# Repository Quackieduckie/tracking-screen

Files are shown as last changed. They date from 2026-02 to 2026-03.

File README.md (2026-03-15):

# Tracking Screen

A screen that follows you around the room. It can be used as a personal assistant, to display data, or simply to watch movies without needing to constantly adjust the angle — it self-calibrates to keep the view optimal.

**Made possible thanks to [PCBWay](https://www.pcbway.com/) for their support in making this project a reality.**

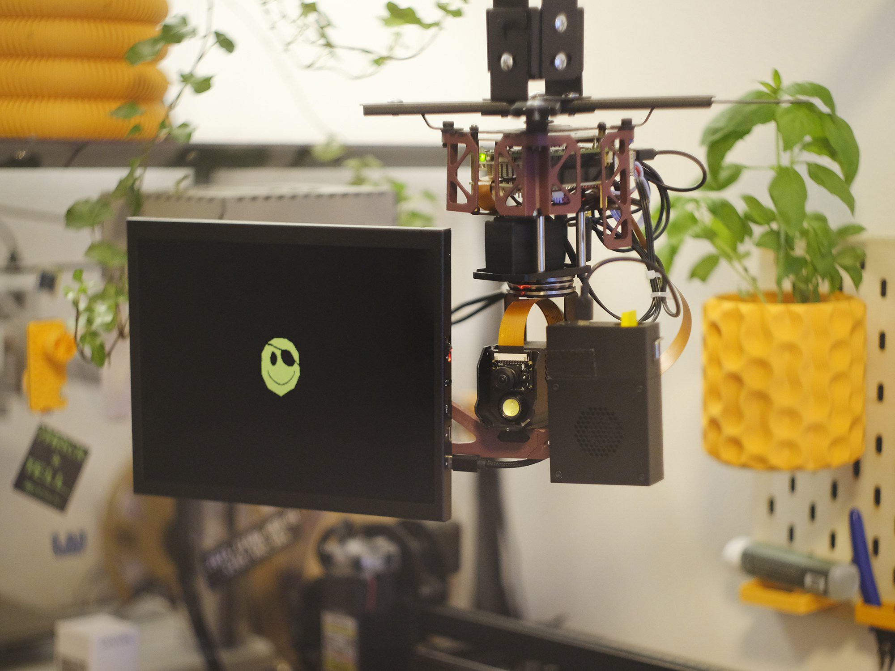
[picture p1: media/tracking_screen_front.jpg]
Tracking Screen


## Background

I first had this idea after catching a cold while visiting my old hackerspace in Berlin, [c-base](https://c-base.org/), and having to spend a few days in bed. I thought it would be cool to have a robotic screen that can track faces, and that you can reposition using hand commands. I could also see this as a kind of digital assistant, although I personally don't see the use case for myself yet.

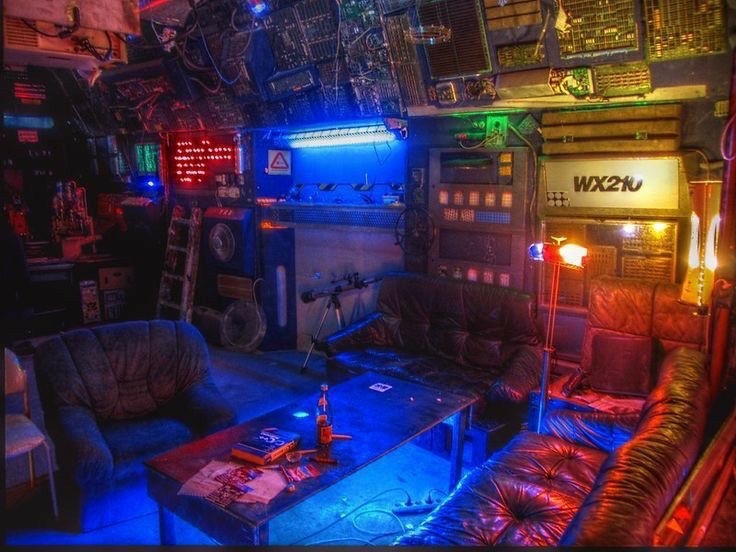
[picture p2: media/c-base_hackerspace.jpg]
c-base hackerspace, Berlin


## Demo

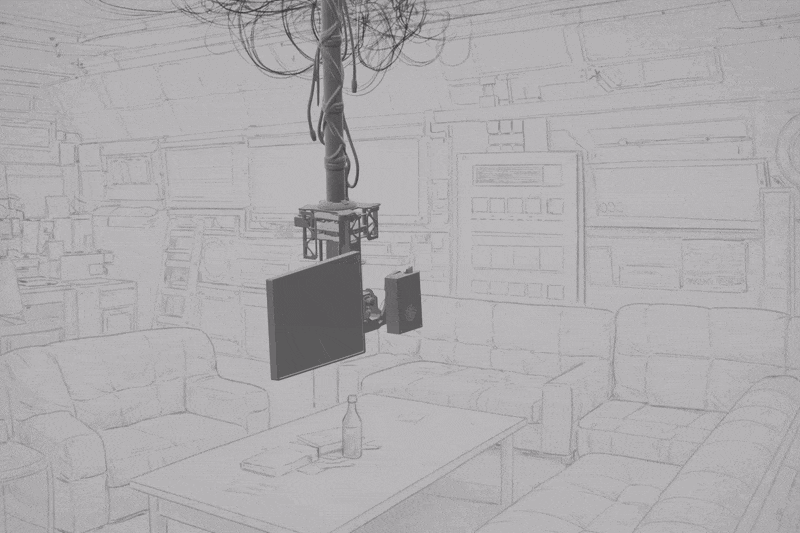
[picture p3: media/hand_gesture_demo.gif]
Hand gesture demo


Hand commands moving the screen to each side. Facial tracking also works in decent enough light — the camera can be upgraded for better range and low-light performance.

## Features

- **Face Detection & Tracking**: Real-time face detection using MediaPipe
- **Gesture Recognition**: Hand gesture detection (palm for left, shaka for right)
- **Smooth Servo Control**: Pan-tilt camera movement with smooth tracking
- **Background Tracking**: Continues scanning when no face is detected
- **Multiple Detection Methods**: Uses both MediaPipe and OpenCV for robust tracking
- **Customizable Configuration**: YAML-based configuration system

## Hardware

### Base Platform

This build is based on the **Waveshare 360° Omnidirectional High-Torque 2-Axis Expandable Pan-Tilt Camera Module**. The module is turned upside down and mounted to a projector holder.

### Components

- Raspberry Pi (4/5 recommended)
- Waveshare 360° Pan-Tilt Camera Module
- [9.7" portable monitor](https://aliexpress.com/item/1005007196893258.html) (or similar — preferably one with VESA mounts)
- IKEA FREKVENS speaker (Teenage Engineering) for audio
- Projector mount or any stable VESA-compatible mount
- Angled HDMI cable (mini male to micro female)

### Mounting Bracket

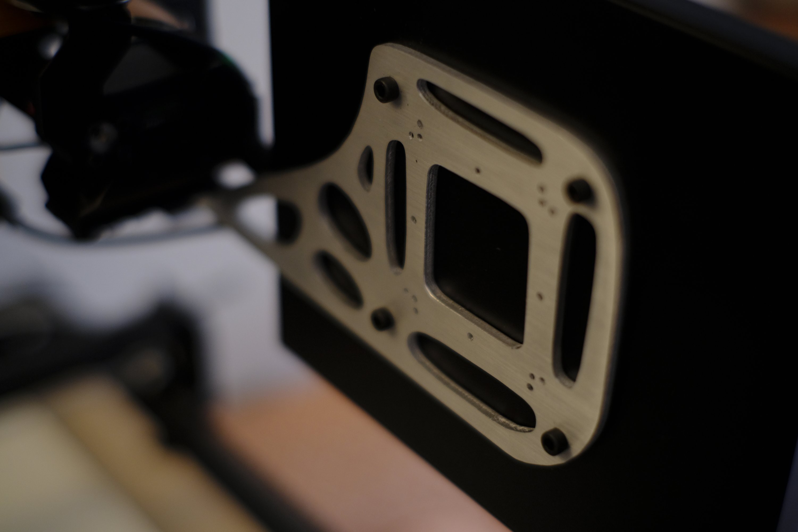
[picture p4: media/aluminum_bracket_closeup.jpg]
Laser-cut aluminum bracket


The SVG for laser-cutting the mounting plate from [4mm aluminum sheet](https://www.pcbway.com/rapid-prototyping/Sheet-metal/Laser-Cutting.html) is included in the `media/` folder. This is surprisingly affordable (under $30 at the time of writing) and significantly more stable than 3D-printed PETG-CF.

The bracket uses a simple topology-optimized design that gives the build an organic Y2K aesthetic. The 3D-printed version can be printed in two parts on a Bambu A1 Mini and superglued together — not perfect, but it holds up well enough if you don't have a large enough build plate.

### Tower Covers

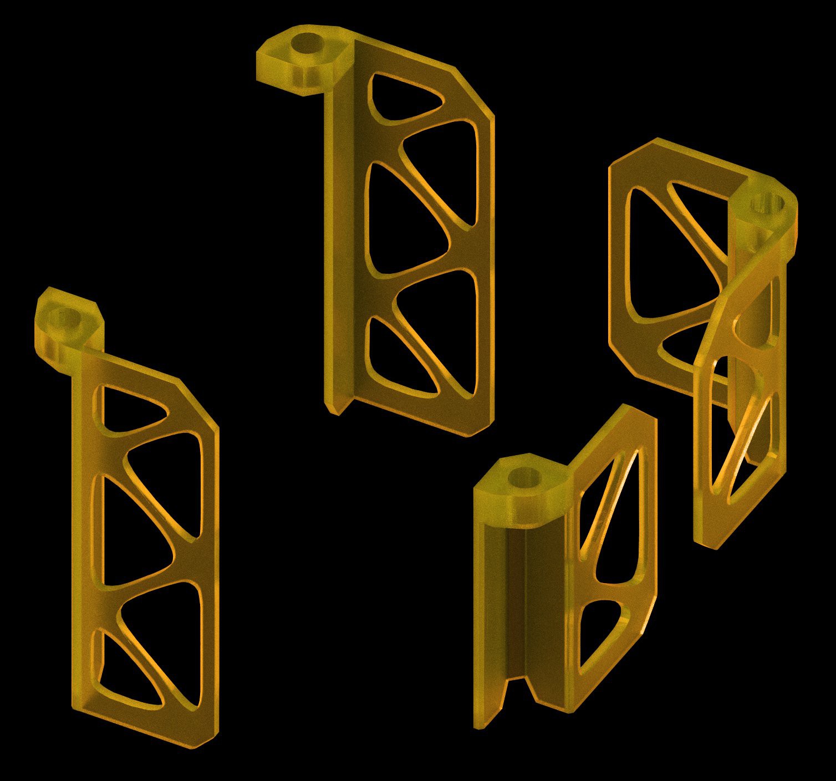
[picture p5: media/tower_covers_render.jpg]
Tower covers render


Optional secondary parts for the tower are included. Originally planned as a full enclosure, but the moving parts required a simplified design. These look great when printed in [UTR Thermal resin](https://www.pcbway.com/rapid-prototyping/3d-printing/plastic/resin/UTR-Therm-1-Resin/) or [SLS aluminum](https://www.pcbway.com/rapid-prototyping/3D-Printing/3D-Printing-SLS.html).

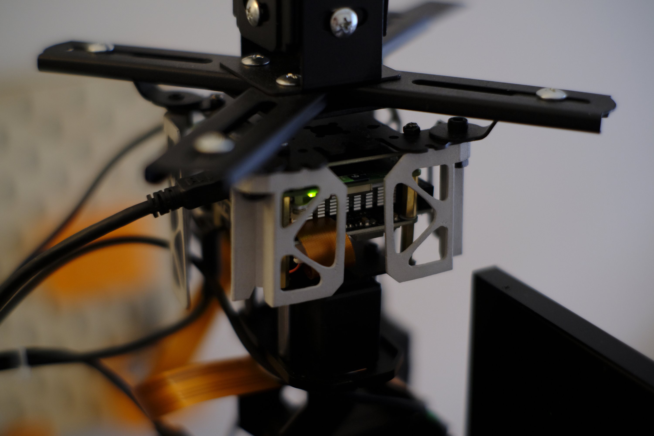
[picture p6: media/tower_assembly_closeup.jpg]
Tower assembly with SLS aluminum covers


### Cabling

Use an **angled HDMI** cable (mini male to micro female), since the screen connection needs extra clearance to fit next to the camera. If you can't find that exact cable, use an adapter on the Raspberry Pi side instead.

## Downloadable Files

| File | Description |
|---|---|
| [`Tracking_Screen_LaserCut_4mm_Aluminium.svg`](media/Tracking_Screen_LaserCut_4mm_Aluminium.svg) | Full backing plate — laser cut from 4mm aluminum |
| [`Tracking_Screen_Backing_Screen.stl`](media/Tracking_Screen_Backing_Screen.stl) | 3D-printable screen backing part |
| [`Tracking_Screen_Backing_Speaker.stl`](media/Tracking_Screen_Backing_Speaker.stl) | 3D-printable speaker backing part |
| [`Tracking_Screen_Covers.stl`](media/Tracking_Screen_Covers.stl) | Cover parts for the tower |

## Software Stack

- **Computer Vision**: OpenCV, MediaPipe
- **Camera**: Picamera2, libcamera
- **Hardware Control**: Custom serial communication with ESP32-based controller
- **Processing**: Multi-threaded CV processing for real-time performance

## Installation

```bash
git clone https://github.com/Quackieduckie/tracking-screen.git
cd tracking-screen
pip3 install -r requirements.txt
nano config.yaml
```

## Configuration

Edit `config.yaml` to customize:

- Camera resolution and FPS
- Servo limits and speeds
- Detection thresholds
- Gesture recognition settings
- Tracking behavior

## Usage

### Basic Face Tracking

```python
from cv_ctrl import OpencvFuncs
from base_ctrl import BaseController

base = BaseController('/dev/ttyAMA0', 115200)
cv = OpencvFuncs('/path/to/project', base)

cv.face_detect_switch(True)
cv.base_ctrl.gimbal_base_ctrl(0, 0)
```

### Gesture Recognition

The system recognizes the following gestures:
- **Palm**: Open hand — move left
- **Shaka**: Hang loose gesture — move right

### Key Functions

**Face Tracking (`cv_ctrl.py`)**:
- `face_detect_switch(True/False)` — Enable/disable face detection
- `tracking_face_on_switch(True/False)` — Enable/disable camera movement
- `gimbal_base_ctrl(x, y)` — Manual camera positioning

**Hardware Control (`base_ctrl.py`)**:
- `gimbal_ctrl(direction, speed)` — Control servos
- `base_json_ctrl(command)` — Send JSON commands to base
- `pwm_servo_ctrl(id, angle)` — Direct servo control

## Technical Details

### Face Detection Pipeline

1. **Initial Detection**: MediaPipe FaceMesh for fast, accurate face detection
2. **Tracking**: Calculates face center and size
3. **Servo Control**: Smooth movement using PID-like control
4. **Background Scanning**: Pan movement when no face detected
5. **Re-acquisition**: Automatic face search behavior

### Performance Optimizations

- Multi-threaded processing
- Efficient frame buffering
- Adaptive FPS adjustment
- Hardware-accelerated encoding (H.264)
- Smart servo movement limits

### Coordinate System

- **X-axis**: Pan (left-right), range: -45° to +45°
- **Y-axis**: Tilt (up-down), range: -30° to +30°
- Center position: (0, 0)

## Project Structure

```
tracking-screen/
├── cv_ctrl.py           # Computer vision and tracking logic
├── base_ctrl.py         # Hardware controller interface
├── config.yaml          # Configuration settings
├── requirements.txt     # Python dependencies
├── models/              # MediaPipe and OpenCV models
├── media/               # Photos, GIF, STL/SVG files
└── README.md
```

## Dependencies

- Python 3.11+
- OpenCV (cv2)
- MediaPipe
- NumPy
- imutils
- Picamera2
- PyYAML
- pyserial

## Links

- **Hackaday project page**: [hackaday.io/project/204828-tracking-screen](https://hackaday.io/project/204828-tracking-screen)
- **More projects**: [enjoythed.biz](https://enjoythed.biz/)

## License

Based on Waveshare UGV example code. See LICENSE file for details.

## Credits

- Original UGV platform: Waveshare
- Custom modifications and enhancements: [@Quackieduckie](https://github.com/Quackieduckie)
- Sponsored hardware (sheet metal backing, SLS aluminum covers): [PCBWay](https://www.pcbway.com/)
- MediaPipe: Google
- OpenCV: OpenCV Foundation

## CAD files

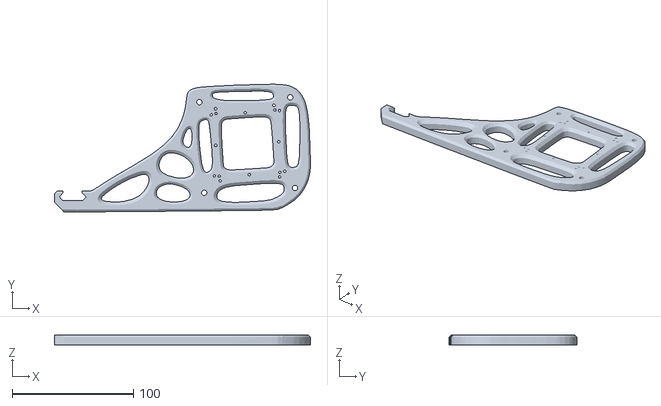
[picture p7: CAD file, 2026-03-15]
media/Tracking_Screen_Backing_Screen.stl
211.2 x 105.3 x 7.98

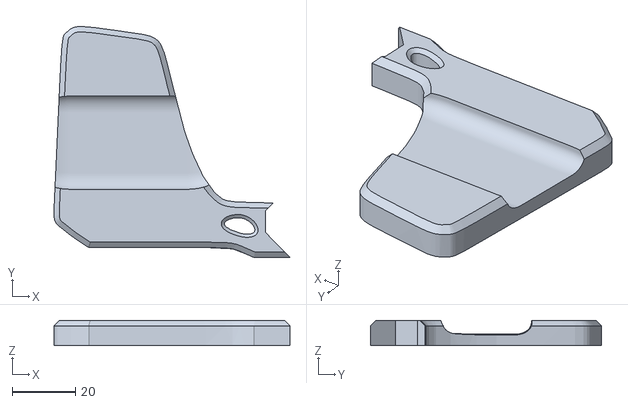
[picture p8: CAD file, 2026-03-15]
media/Tracking_Screen_Backing_Speaker.stl
74.5 x 72.9 x 7.98

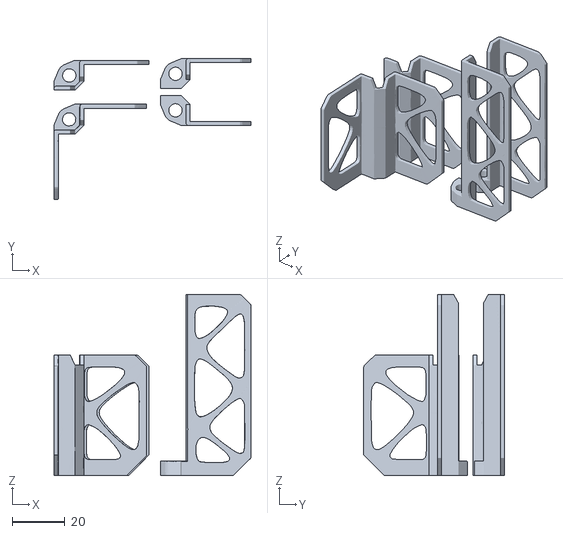
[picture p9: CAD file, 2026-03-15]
media/Tracking_Screen_Covers.stl
75.0 x 53.5 x 69.0

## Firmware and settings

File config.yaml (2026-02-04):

args_config:
  arm_default_e: 60
  arm_default_r: 0
  arm_default_z: 24
  max_rate: 1.0
  max_speed: 1.3
  mid_rate: 0.66
  min_rate: 0.3
  slow_speed: 0.2
audio_config:
  audio_output: true
  default_volume: 1.0
  min_time_bewteen_play: 1
  speed_rate: 180
base_config:
  add_osd: false
  extra_sensor: false
  main_type: 2
  module_type: 0
  robot_name: UGV Rover
  sbc_version: 0.93
  use_lidar: false
cmd_config:
  cmd_arm_ctrl_ui: 144
  cmd_gimbal_base_ctrl: 141
  cmd_gimbal_ctrl: 133
  cmd_gimbal_steady: 137
  cmd_movition_ctrl: 1
  cmd_pwm_ctrl: 11
  cmd_servo_torque: 210
  cmd_set_servo_id: 501
  cmd_set_servo_mid: 502
code:
  base_ct: 10410
  base_of: 10407
  base_on: 10408
  cv_auto: 10307
  cv_clor: 10305
  cv_face: 10303
  cv_moti: 10302
  cv_none: 10301
  cv_objs: 10304
  head_ct: 10409
  led_aut: 10405
  led_off: 10404
  led_ton: 10406
  max_res: 10101
  mc_lock: 10501
  mc_unlo: 10502
  mid_res: 10102
  min_res: 10103
  mp_face: 10308
  mp_hand: 10306
  mp_pose: 10309
  pic_cap: 10201
  re_capt: 10402
  re_none: 10401
  re_reco: 10403
  release: 10902
  s_panid: 10901
  s_tilid: 10904
  set_mid: 10903
  vid_end: 10203
  vid_sta: 10202
  zoom_x1: 10104
  zoom_x2: 10105
  zoom_x4: 10106
cv:
  aimed_error: 60
  color_lower:
  - 101
  - 50
  - 38
  color_upper:
  - 110
  - 255
  - 255
  default_color: blue
  min_radius: 12
  sampling_rad: 25
  track_acc_rate: 0.4
  track_color_iterate: 0.023
  track_faces_iterate: 0.055
  track_spd_rate: 60
fb:
  base_light: 115
  base_voltage: 112
  cpu_load: 106
  cpu_temp: 107
  cv_movtion_mode: 114
  detect_react: 103
  detect_type: 101
  led_mode: 102
  pan_angle: 109
  picture_size: 104
  ram_usage: 108
  tilt_angle: 110
  video_fps: 113
  video_size: 105
  wifi_rssi: 111
sbc_config:
  disabled_http_log: true
  feedback_interval: 0.001
video:
  default_quality: 20
  default_res_h: 480
  default_res_w: 640

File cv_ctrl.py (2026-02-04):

import cv2
import imutils
import mediapipe as mp
import imageio
import threading
import datetime, time
import numpy as np
import math
import yaml, os, json, subprocess
from collections import deque
import textwrap

# libraries for csi camera
from picamera2 import Picamera2
from picamera2.encoders import H264Encoder, Encoder
from picamera2.outputs import FfmpegOutput
from libcamera import Transform

# libraries for oak camera
import depthai as dai

# config file.
curpath = os.path.realpath(__file__)
thisPath = os.path.dirname(curpath)
with open(thisPath + '/config.yaml', 'r') as yaml_file:
    f = yaml.safe_load(yaml_file)


class OpencvFuncs():
    """docstring for OpencvFuncs"""
    def __init__(self, project_path, base_ctrl):
        self.base_ctrl = base_ctrl
        self.cv_event = threading.Event()
        self.cv_event.clear()
        self.cv_mode = f['code']['cv_none']
        self.detection_reaction_mode = f['code']['re_none']
        
        self.this_path = project_path
        self.photo_path = self.this_path + '/templates/pictures/'
        self.video_path = self.this_path + '/templates/videos/'
        self.frame_scale = 1
        self.picture_capture_flag = False
        self.set_video_record_flag = False
        self.video_record_status_flag = False
        self.writer = None
        self.overlay = None
        self.scale_rate = 1
        self.video_quality = f['video']['default_quality']

        # cv ctrl info
        self.cv_light_mode = 0
        self.pan_angle = 0
        self.gesture_lock_active = False  # Lock face tracking after palm gesture
        self.tilt_angle = 0
        self.video_fps = 0
        self.fps_start_time = time.time()
        self.fps_count = 0
        self.cv_movtion_lock = False  # Allow servo tracking by default
        self.aimed_error = f['cv']['aimed_error']
        self.track_spd_rate = f['cv']['track_spd_rate']
        self.track_acc_rate = f['cv']['track_acc_rate']
        self.CMD_GIMBAL = f['cmd_config']['cmd_gimbal_ctrl']
        self.sampling_rad = f['cv']['sampling_rad']

        # reaction
        self.last_frame_capture_time = datetime.datetime.now()
        self.last_movtion_captured = datetime.datetime.now()
        # Motion tracking cycle variables (pause-scan-move-pause)
        self.motion_scan_duration = 3.0  # Scan for motion for 3 seconds
        self.motion_pause_duration = 3.0  # Pause after moving for 3 seconds
        self.motion_cycle_start = datetime.datetime.now()
        self.motion_cycle_state = "scanning"  # States: "scanning", "moving", "paused"
        self.motion_detected_position = None
        self.motion_accumulated_detections = []
        # Face tracking cycle variables (pause-scan-move)
        self.face_scan_duration = 1.2  # Scan for faces (faster cycle)
        self.face_pause_duration = 0.8  # Pause after moving for settling (reduced)
        self.face_cycle_start = datetime.datetime.now()
        self.face_cycle_state = "scanning"  # States: "scanning", "moving", "paused"
        self.face_detected_position = None
        self.face_detected_area = 0

        # movtion detection
        self.avg = None

        # face detection & tracking
        self.faceCascade = cv2.CascadeClassifier(thisPath + '/models/haarcascade_frontalface_default.xml')
        self.min_radius = f['cv']['min_radius']
        self.track_faces_iterate = f['cv']['track_faces_iterate']

        # color detection
        self.points = deque(maxlen=32)
        self.color_list = {
                        'red':  [np.array([  0,200, 170]), np.array([ 10, 255, 255])],
                        'green':[np.array([ 50, 130, 130]), np.array([ 78, 255, 255])],
                        'blue': [np.array([ 90,160, 150]), np.array([105, 255, 255])]
                        }
        if f['cv']['default_color'] in self.color_list:
            self.color_lower = self.color_list[f['cv']['default_color']][0]
            self.color_upper = self.color_list[f['cv']['default_color']][1]
        else:
            self.color_lower = np.array(f['cv']['color_lower'])
            self.color_upper = np.array(f['cv']['color_upper'])
        self.track_color_iterate = f['cv']['track_color_iterate']

        # cv_dnn_objects
        self.net = cv2.dnn.readNetFromCaffe(thisPath + '/models/deploy.prototxt', thisPath + '/models/mobilenet_iter_73000.caffemodel')
        self.class_names = ["background", "aeroplane", "bicycle", "bird", "boat",
                            "bottle", "bus", "car", "cat", "chair", "cow", "diningtable",
                            "dog", "horse", "motorbike", "person", "pottedplant", "sheep",
                            "sofa", "train", "tvmonitor"]

        # mediapipe
        self.mpDraw = mp.solutions.drawing_utils

        # mediapipe detect hand
        self.mpHands = mp.solutions.hands
        self.hands = self.mpHands.Hands(max_num_hands=1)
        self.max_distance = 1
        self.gs_pic_interval = 6
        self.gs_pic_last_time = time.time()

        # findline autodrive
        self.sampling_line_1 = 0.6
        self.sampling_line_2 = 0.9
        self.slope_impact = 1.5
        self.base_impact = 0.005
        self.speed_impact = 0.5
        self.line_track_speed = 0.3
        self.slope_on_speed = 0.1
        self.line_lower = np.array([25, 150, 70])
        self.line_upper = np.array([42, 255, 255])

        # mediapipe detect faces
        self.mp_face_detection = mp.solutions.face_detection
        self.face_detection = self.mp_face_detection.FaceDetection(model_selection=0, min_detection_confidence=0.5)

        # mediapipe detect pose
        self.mp_pose = mp.solutions.pose
        self.pose = self.mp_pose.Pose(static_image_mode=False, 
                                    model_complexity=1, 
                                    smooth_landmarks=True, 
                                    min_detection_confidence=0.5, 
                                    min_tracking_confidence=0.5)

        # base data
        self.show_base_info_flag = False
        self.recv_deque = deque(maxlen=20)

        # info update
        self.show_info_flag = True
        self.info_update_time = time.time()
        self.info_deque = deque(maxlen=10)
        self.info_scale = 270 / 480
        self.info_bg_color = (0, 0, 0)
        self.info_show_time = 10
        self.recv_line_max = 26

        # mission funcs
        self.mission_flag = False

        # osd settings
        self.add_osd = f['base_config']['add_osd']

        # camera type detection
        self.usb_camera_connected = self.usb_camera_detection()
        self.csi_camera_connected = False
        self.oak_camera_connected = False

        # usb camera init
        if self.usb_camera_connected:
            self.camera = cv2.VideoCapture(0)
            self.camera.set(cv2.CAP_PROP_FRAME_WIDTH, f['video']['default_res_w'])
            self.camera.set(cv2.CAP_PROP_FRAME_HEIGHT, f['video']['default_res_h'])
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

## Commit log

2026-02-04 Initial commit: Face tracking camera system with MediaPipe and gesture recognition
2026-02-04 Add acknowledgment to PCBWay for project support
2026-03-15 Add project photos, build files, and detailed README from Hackaday
    Enriched README with full project description, background story,
    hardware build guide, assembly instructions, and downloadable files
    table sourced from the Hackaday project page. Added gallery images
    (front view, bracket closeup, tower assembly, cover renders, c-base
    hackerspace, gesture demo GIF) and fabrication files (laser-cut SVG,
    STL parts) to the media folder. Updated .gitignore to allow media
    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
    [Tracking_Screen_Backing_Screen.stl, Tracking_Screen_Backing_Speaker.stl, Tracking_Screen_Covers.stl]
